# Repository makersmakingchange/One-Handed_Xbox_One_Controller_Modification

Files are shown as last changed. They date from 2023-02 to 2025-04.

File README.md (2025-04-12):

<!--- Open Source Assistive Technology: GitHub Readme Template --->

<!---INSTRUCTIONS  This is a markdown template for creating the README.md file in a GitHub repository. This file is rendered and displayed automatically when someone visits the repository.
This document includes helper text that will not be displayed when rendered. Any text between the less-than sign + exclamation mark + three hyphen-minus (<!---) and matching three hyphen-minus + greater-than sign will not be displayed. This helper text can be deleted once the corresponding section is completed.
--->
 
<!--- TITLE Should match the name of the GitHub repository. Choose something descriptive rather than whimsical.  --->
 # One-Handed Mods for Xbox One Controller

<!--- SUMMARY A brief summary of the project. What it does, who it is for, how much it costs.  --->
This inexpensive 3D printed modification for the Xbox One controller will allow for the user to operate their Xbox One controller with one hand. This controller adaptation makes it easier for someone who may have a difficult time holding a controller with both hands, or has greater dexterity with one hand than the other. The modification is removable; no permanent modifications to the controller are required. There are two versions of the modifier: one for use with the right hand, one for use with the left hand.

<!--- PHOTO  --->
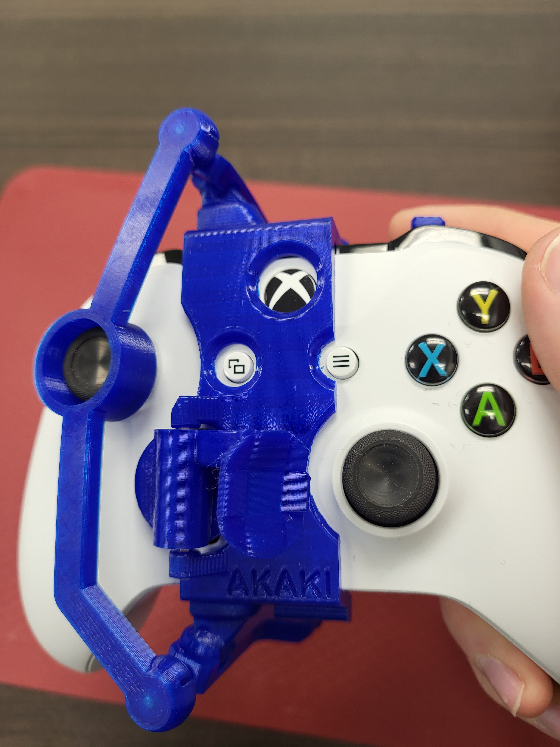
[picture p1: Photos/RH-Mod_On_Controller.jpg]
Right Hand Mod on Xbox One Controller.


## More info at
  - [Makers Making Change Project Page](https://makersmakingchange.com/project/one-handed-mods-for-xbox-one-controller/)

## Getting Started
<!---  Include an overall idea of what major steps are required to build the device.  --->

### 1. Print the 3D Printable components
Print the components for the switch tester case and choose an option for the case.

All of the files and individual print files can be in the [/Build_Files/3D_Printing_Files](/Build_Files/3D_Printing_Files/) folder.

### 2. Assemble the One-Handed Mod for Xbox One Controller
Reference the Assembly Guides in the [Documentation](/Documentation) folder for the tools and steps required to build each portion.

## Files
<!--- FILES This section includes all the information and files required to build and modify the device, including documentation, design files, and build files. --->

### Documentation
<!--- DOCUMENTATION  --->
| Document | Version | Link |
|---|---|---|
| Bill of Materials | 1.0 | [One-Handed_Mods_BOM](/Documentation/Working_Documents/One-Handed_Mods_for_Xbox_One_Controller_BOM.xlsx) |
| Left-Hand Mod Assembly Guide | 1.0 | [Left-Hand_Mod_Instructions](/Documentation/Left-Handed_Mod_for_Xbox_One_Controller_Assembly_Guide.pdf) |
| Right-Hand Mod Assembly Guide | 1.0 | [Right-Hand_Mod_Instructions](/Documentation/Right-Handed_Mod_for_Xbox_One_Controller_Assembly_Guide.pdf) |
| Maker Checklist | 1.0 | [One-Handed_Mods_Checklist](/Documentation/One-Handed_Mods_for_Xbox_One_Controller_Maker_Checklist.pdf) |
| User Quick Guide | 1.0 | [One-Handed_Mods_Quick_Guide](/Documentation/One-Handed_Mods_for_Xbox_One_Controller_User_Guide.pdf) |
| Changelog | 1.0 | [One-Handed_Mods_Changelog](/Documentation/One-Handed_Mods_for_Xbox_One_Controller_Changelog.pdf) |

### Build Files
<!--- BUILD FILES --->
 - [3D Printing Files](/Build_Files/3D_Printing)

## License
<!--- LICENSE Choose an appropriate license. We recommend an open-source hardware compatible license. --->
Everything needed or used to design, make, test, or prepare the One-Handed Mods for Xbox One Controller is licensed under a Creative Commons Attribution-NonCommercial-ShareAlike 4.0 International license.

Accompanying material by Makers Making Change, such as instruction manuals, are published under a Creative Commons Attribution-ShareAlike 4.0 license <https://creativecommons.org/licenses/by-sa/4.0/> (CC BY-SA 4.0).

## Attribution
<!--- ATTRIBUTION Include any information related to the development of the design. This may include who identified the initial challenge, who contributed to the design --->
Designed and remixed by [Akaki](https://www.printables.com/social/106360-akaki/about).

The documentation template was created by Makers Making Change and is used under a CC BY-SA 4.0 license. It is available at the following link: https://github.com/makersmakingchange/OpenAT-Template

----

<!-- ABOUT MMC START -->
## About Makers Making Change
[Makers Making Change Logo](https://www.makersmakingchange.com/)

Makers Making Change is a program of [Neil Squire](https://www.neilsquire.ca/), a Canadian non-profit that uses technology, knowledge, and passion to empower people with disabilities.

Makers Making Change leverages the capacity of community based Makers, Disability Professionals and Volunteers to develop and deliver affordable Open Source Assistive Technologies.

 - Website: [www.MakersMakingChange.com](https://www.makersmakingchange.com/)
 - GitHub: [makersmakingchange](https://github.com/makersmakingchange)
 - Bluesky: [@makersmakingchange.bsky.social](https://bsky.app/profile/makersmakingchange.bsky.social)
 - Instagram: [@makersmakingchange](https://www.instagram.com/makersmakingchange)
 - Facebook: [makersmakechange](https://www.facebook.com/makersmakechange)
 - LinkedIn: [Neil Squire Society](https://www.linkedin.com/company/neil-squire-society/)
 - Thingiverse: [makersmakingchange](https://www.thingiverse.com/makersmakingchange/about)
 - Printables: [MakersMakingChange](https://www.printables.com/@MakersMakingChange)

### Contact Us
For technical questions, to get involved, or to share your experience we encourage you to [visit our website](https://www.makersmakingchange.com/) or [contact us](https://www.makersmakingchange.com/s/contact).
<!-- ABOUT MMC END -->

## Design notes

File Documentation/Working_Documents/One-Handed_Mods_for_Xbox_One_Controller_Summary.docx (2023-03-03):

# Title

One-Handed Mods for Xbox One Controller

## Subtitle

3D printed Modifications to make an Xbox One controller accessible with either your right or left hand only.

## Device Specifications

Build Time:

< 1hr

1-4 hr

5-10hr

>10hr

Cost:

$0 - $10

$11 - $25

$26 - $50

$51 - $100

$101 - $250

$250+

Stage:

Skills:

Need:

Disability:

Difficulty:

License:

Usages:

Type:

Designer:

## Device Details

### Overview

This inexpensive 3D printed modification for the Xbox One controller will allow for the user to operate their Xbox One controller with one hand. This controller adaptation makes it easier for someone who may have a difficult time holding a controller with both hands, or has greater dexterity with one hand than the other.

### Compatibility

Note that the Xbox controllers can be used on PC based gaming and can be used with a Nintendo Switch with the correct adapter.

Platforms: Xbox Series X|S, Xbox One, Xbox 360, PC, Nintendo Switch (with a similar adapter (https://www.amazon.ca/Mayflash-Magic-NS-Wireless-Controller-Nintendo/dp/B079B5KHWQ?hvadid=292937839648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)).

Controllers: Xbox One Controllers

### Usage

This controller adaptation allows for the user to operate their Xbox Series X|S controller with only one hand. For a left handed controller, the right joystick is used by moving the whole controller. By moving the controller, the 3D printed parts enable the joystick to move simultaneously. In addition, the right shoulder buttons are migrated to the left side so all four shoulder buttons can be used with the index finger. Similarly, four 3D printed arms are used to allow the user to press the A, B, X, Y, and home buttons from the left side.

There are two different attachments for the bottom of the controller shown below that can be used depending on whether the user chooses to strap the controller to their leg (right), or can rest it on their lap or a surface of their choice using the “shoe” (left).

### Build Instructions

#### A set of instructions for assembling this modification for the Xbox One controller can be found through our GitHub Repository and through the YouTube assembly video (https://www.youtube.com/watch?v=QOOU2KnhcHA) linked above.

#### The Xbox One controller is asymmetrical, so this controller modification has different files for the left and right-handed modifications.

#### Skills Required

- 3D printing

#### Tools

- 3D printer
- Scissors

Optional:

- Rubber bands can be added to the bottom piece of the controller (shoe) to increase grip strength.
- Raw filament can be cut and used as pin joints between some of the pieces.
- Sandpaper to smooth the ball and socket joints.
- Vaseline to lubricate the ball and socket joints.

#### 3D Printing

All components can be printed with no support at 20% infill with a 0.2mm layer height. All pieces can be printed using PLA filament. If possible, it is recommended to print the “shoe” piece in TPU, but if printed in PLA add rubber bands around the piece for additional grip. 3D print files can be found on the Prusa Printers’ website and are linked above.

Note that all necessary components for the left and right-handed modifications (including the leg mount) are included in their respective print files.

Optional files:

- 1x Shoe (optional replacement to leg mount)
- 1x Button Decorations (optional and only for the left handed modification)

### Attribution

Designed and Remixed from the Xbox Series X|S mod (https://makersmakingchange.com/project/one-handed-mod-xbox-series-xs-controller/) by: Akaki (https://www.prusaprinters.org/social/106360-akaki/about)

Released under Creative Commons Attribution-Noncommercial-ShareAlike 4.0 International license.

© 2022 by <Author>. This work is licensed under the CC BY SA 4.0 License: http://creativecommons.org/licenses/by-sa/4.0 Files available at <Replace with MMC Library Link> Page 1 of 2

V1.0 | February 2023 One-Handed Mod for Xbox One Controller Summary

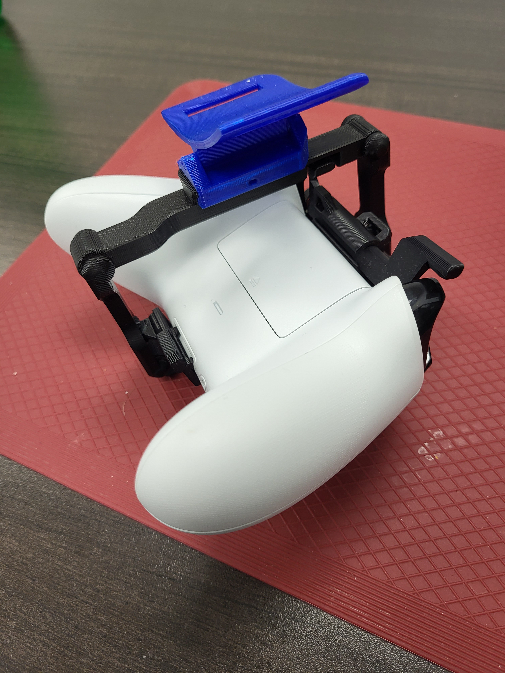
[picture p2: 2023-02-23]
Photos/LH-Mod_With_Leg_Mount.jpg

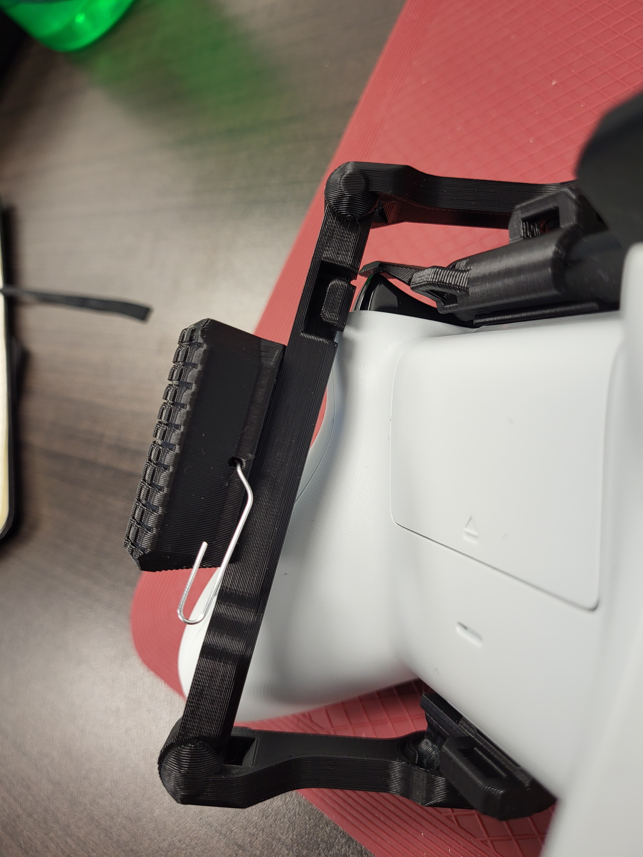
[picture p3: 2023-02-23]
Photos/LH-Mod_With_Shoe.jpg

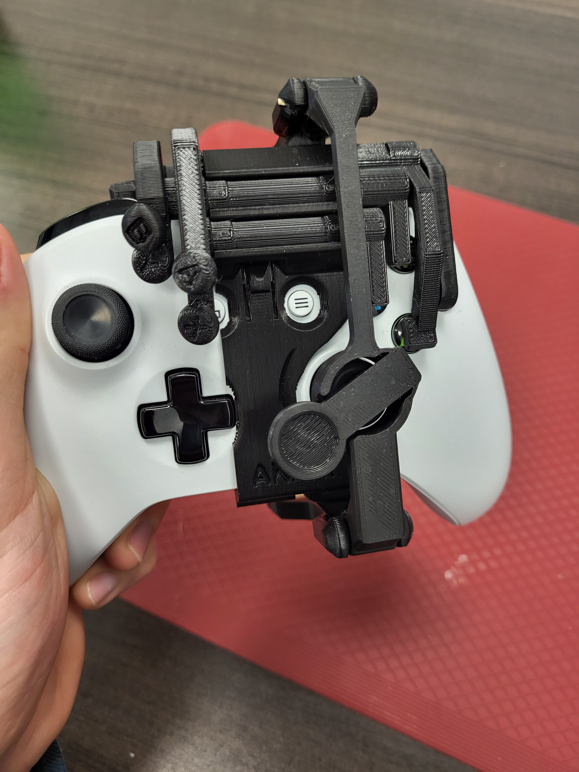
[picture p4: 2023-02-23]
Photos/LH-Mod_On_Controller.jpg

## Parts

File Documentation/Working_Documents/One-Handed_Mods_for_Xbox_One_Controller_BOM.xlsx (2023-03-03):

One-Handed Mods for Xbox One Controller |  |  |  |  |  |  |  | Unit Cost | Total Cost | Total Print time (hr) | Total filament (g)
Version: V1.0 |  | Last Updated: 2023-02-23 |  |  |  |  |  | $3.43 | $0.00 | 0.00 | 137.31
Commercial Parts
ID | Part Name | Part Type | QTY | QTY/PKG | $/PKG | PKG QTY | $/Unit | Extended | Total | Link
 |  |  |  |  | $0.00 | 0 | $0.00 | $0.00 | $0.00
 |  |  |  |  | $0.00 | 0 | $0.00 | $0.00 | $0.00
 |  |  |  |  | $0.00 | 0 | $0.00 | $0.00 | $0.00
 |  |  |  |  | $0.00 | 0 | $0.00 | $0.00 | $0.00
 |  |  |  |  | $0.00 | 0 | $0.00 | $0.00 | $0.00
 |  |  |  |  | $0.00 | 0 | $0.00 | $0.00 | $0.00
 |  |  |  |  | $0.00 | 0 | $0.00 | $0.00 | $0.00
3D Printed Parts ESTIMATED PRICING USING 1KG ROLL COST: |  | $25.00
ID | Part | Material | QTY | Mass (g) / Unit | Time / Unit |  | Print Time (Min) | Estimated Price |  | Link
 | Left-Handed Mod | PLA | 1 | 66.56 | 7h13m |  | 7h13m | $1.66
 | Right-Handed Mod | PLA | 1 | 45.26 | 4h46m |  | 4h46m | $1.13
 | Shoe | PLA | 1 | 11.62 | 1h22m |  | 1h22m | $0.29
 | Leg Mount | PLA | 1 | 13.87 | 1h26 |  | 1h26 | $0.35
 |  |  |  |  |  |  |  | $0.00
 |  |  |  |  |  |  |  | $0.00
Custom Printed Circuit Board (PCB)
ID | Part |  | QTY
Tools for Assembly
 | Glue
Alternatives (if there are other sources for some parts link them below)
ID | Part and description |  |  |  |  |  |  |  |  | Link

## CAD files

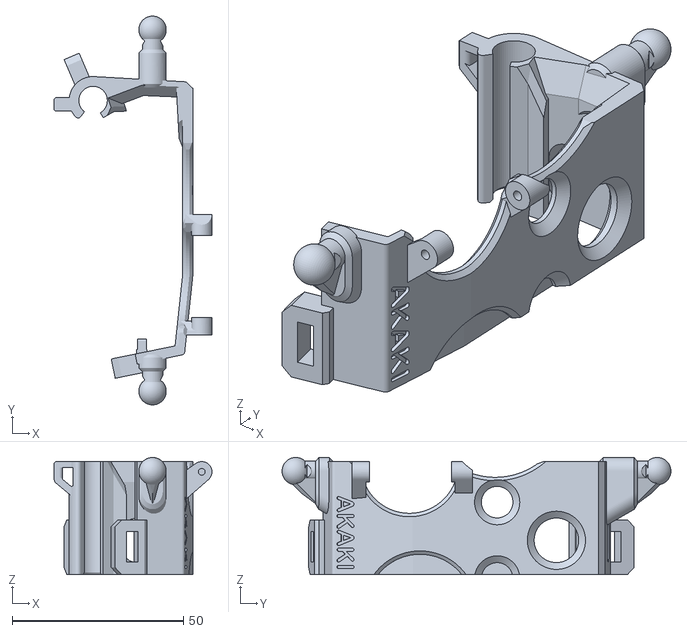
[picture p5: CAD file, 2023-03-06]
Build_Files/3D_Printing_Files/Right-Handed Mod/RH-Main_Housing_Piece.stl
46.2 x 113.6 x 34.2

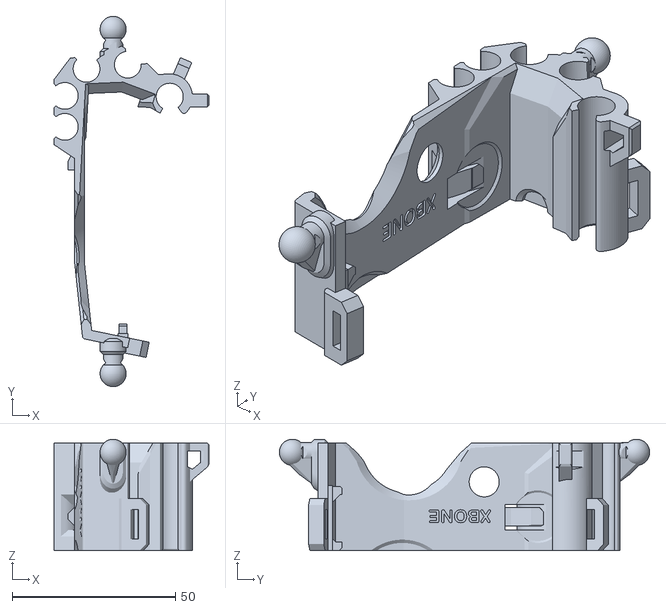
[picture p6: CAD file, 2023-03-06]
Build_Files/3D_Printing_Files/Left-Handed Mod/LH-Main_Housing_Piece.stl
47.5 x 113.6 x 34.2

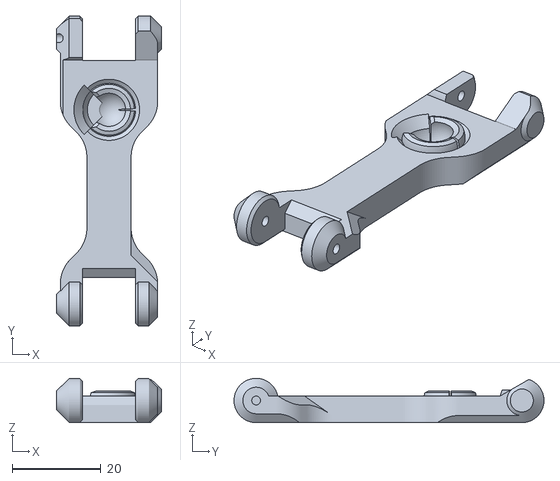
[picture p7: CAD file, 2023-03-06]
Build_Files/3D_Printing_Files/Left-Handed Mod/LH-Top_Ball_n_Socket_Connector.stl
23.6 x 70.0 x 10.00

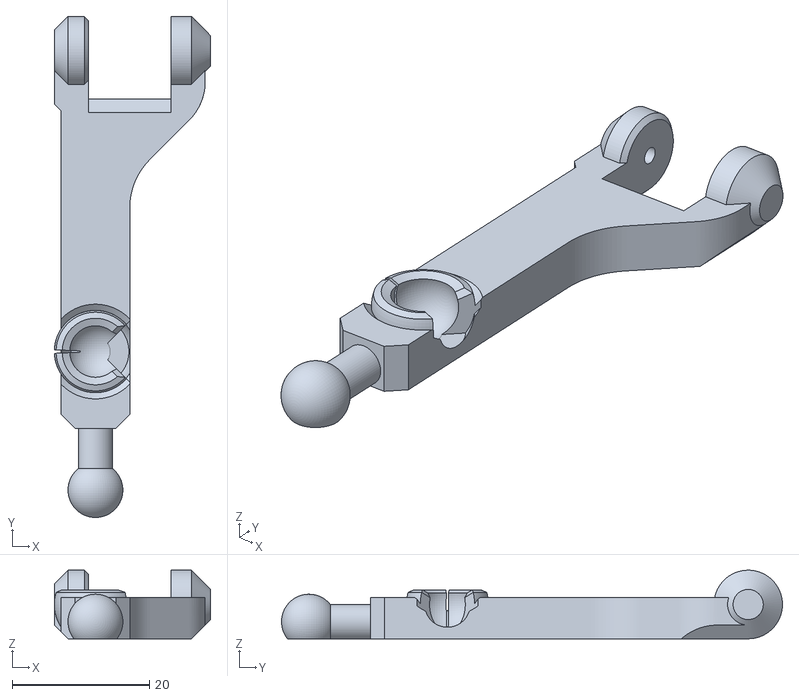
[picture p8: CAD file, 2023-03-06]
Build_Files/3D_Printing_Files/Right-Handed Mod/RH-Bottom_Ball_n_Socket_Connector.stl
22.8 x 73.0 x 10.00

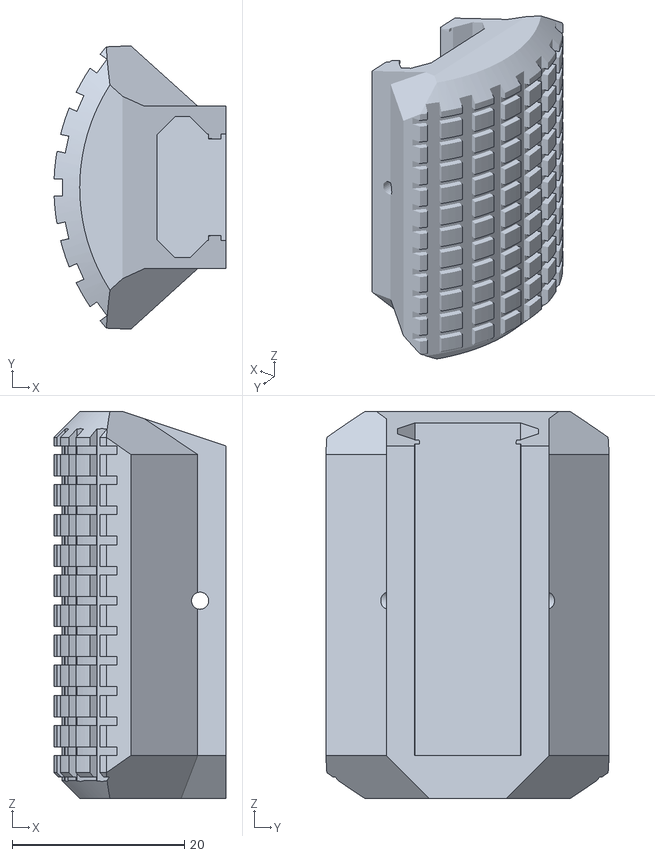
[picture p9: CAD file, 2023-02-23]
Build_Files/3D_Printing_Files/shoe.stl
20.0 x 33.0 x 45.0

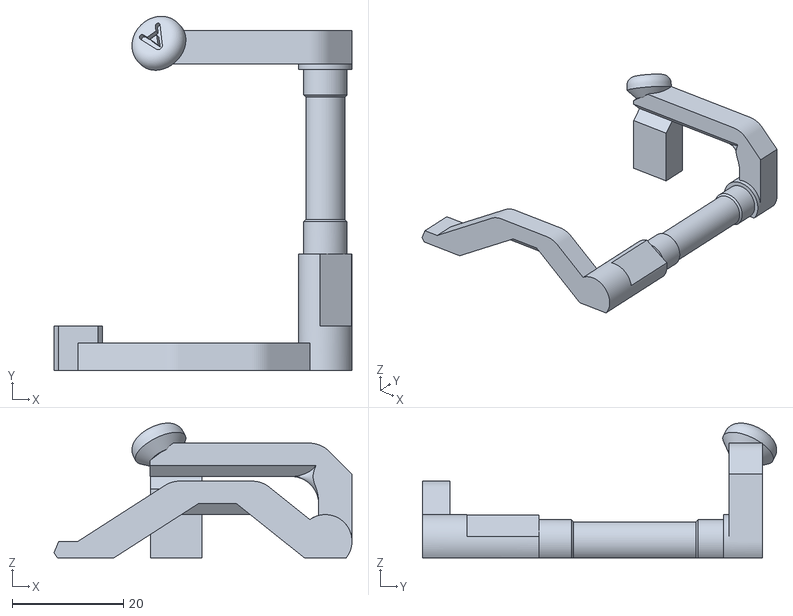
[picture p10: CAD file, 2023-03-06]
Build_Files/3D_Printing_Files/Left-Handed Mod/LH-A_Button_Extender.stl
53.6 x 63.8 x 24.3

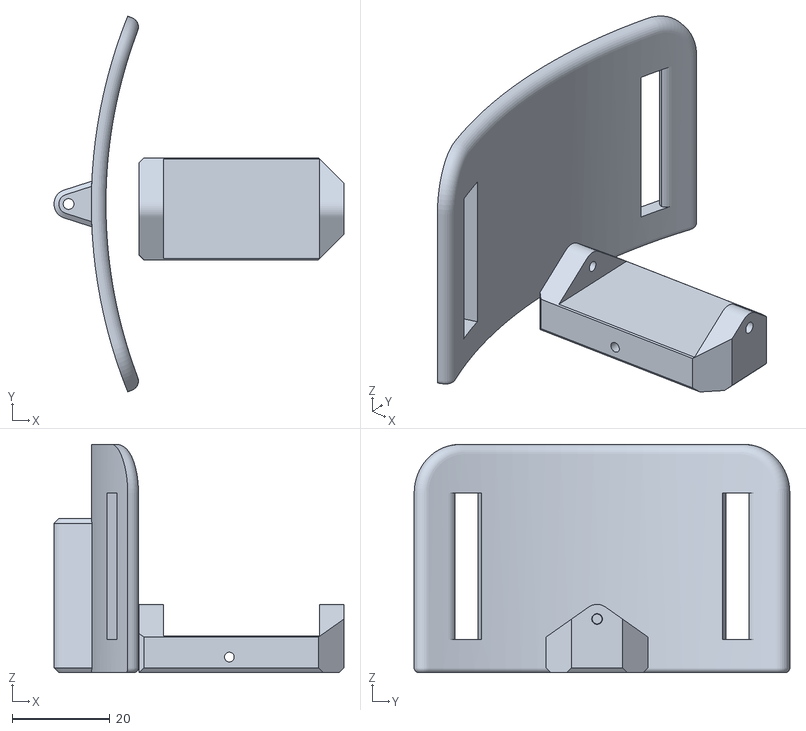
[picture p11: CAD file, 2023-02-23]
Build_Files/3D_Printing_Files/leg mount.stl
59.4 x 77.0 x 46.8

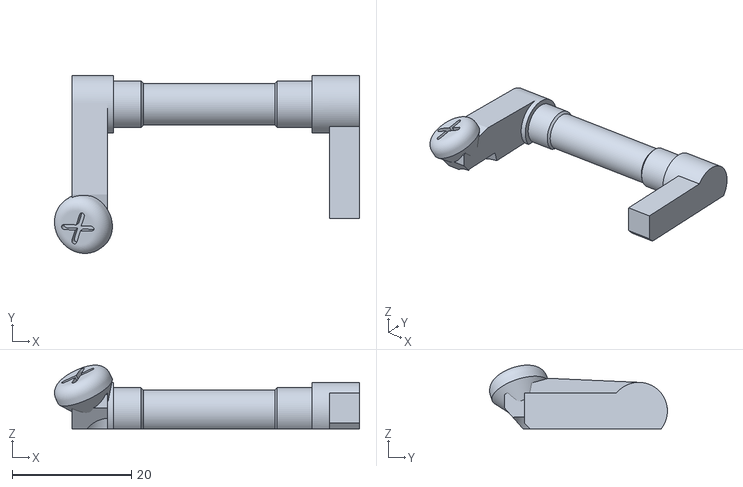
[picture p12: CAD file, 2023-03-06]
Build_Files/3D_Printing_Files/Left-Handed Mod/LH-X_Button_Extender.stl
51.1 x 29.8 x 10.7

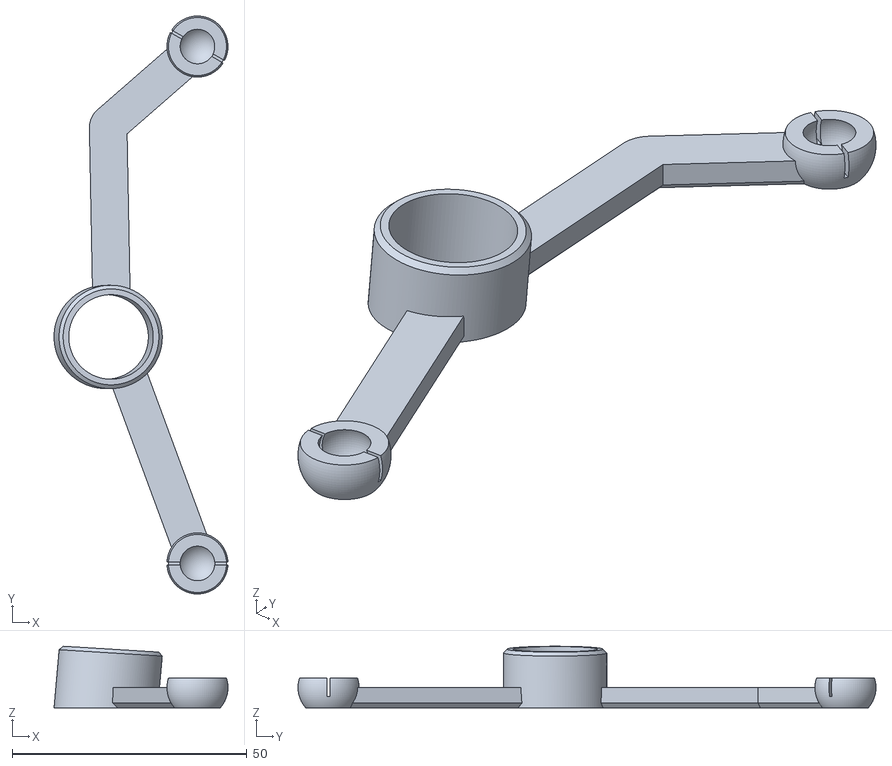
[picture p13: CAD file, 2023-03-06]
Build_Files/3D_Printing_Files/Right-Handed Mod/RH-Thumstick_Arm.stl
37.0 x 123.0 x 13.1

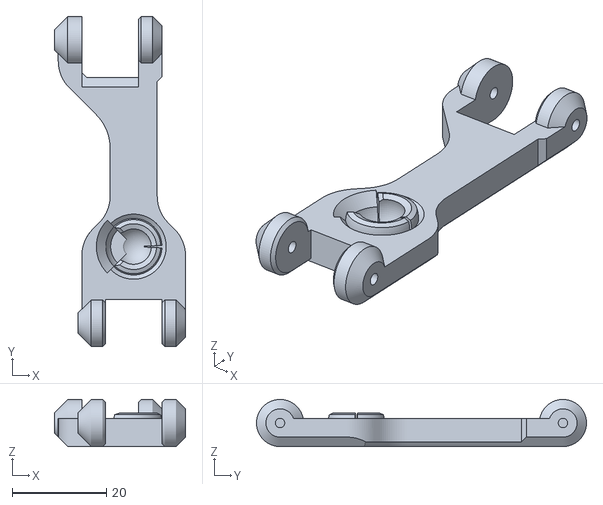
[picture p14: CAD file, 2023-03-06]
Build_Files/3D_Printing_Files/Left-Handed Mod/LH-Bottom_Ball_n_Socket_Connector.stl
27.8 x 70.0 x 10.00

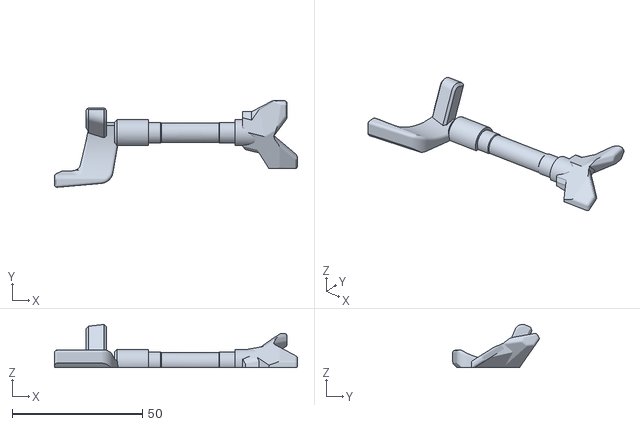
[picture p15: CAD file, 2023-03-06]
Build_Files/3D_Printing_Files/Right-Handed Mod/RH-Trigger_Extender.stl
93.2 x 33.2 x 16.5

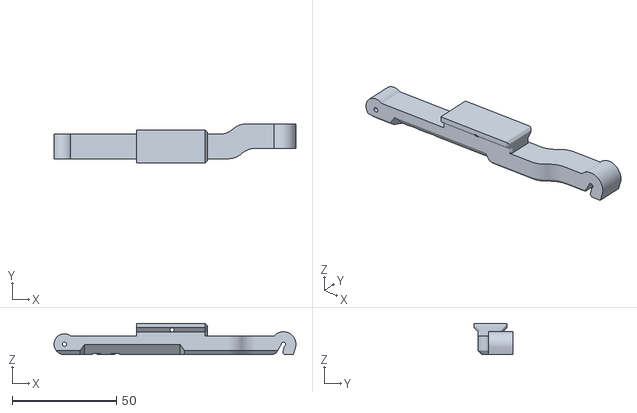
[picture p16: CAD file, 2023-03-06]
Build_Files/3D_Printing_Files/Left-Handed Mod/LH-Rear_Connecting_Arm.stl
116.0 x 18.9 x 15.0

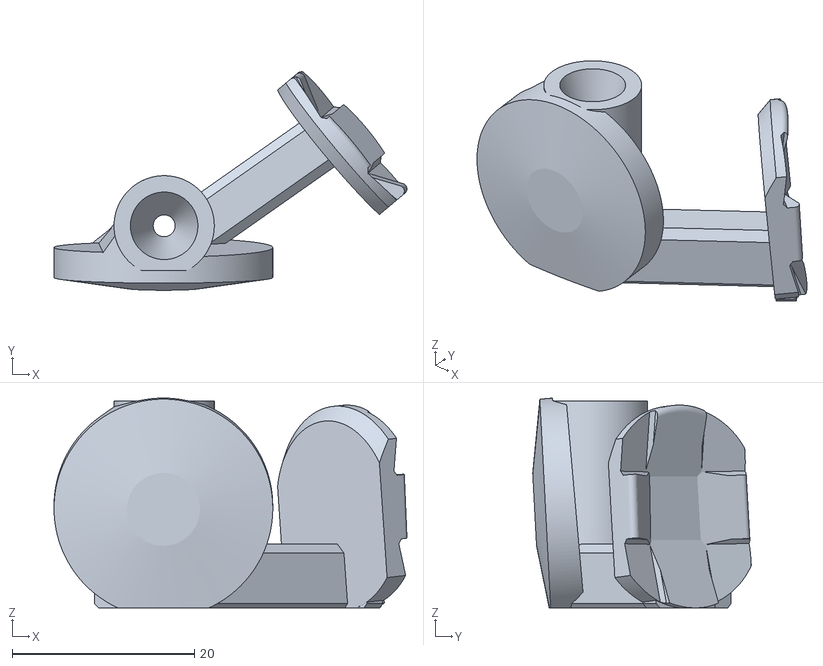
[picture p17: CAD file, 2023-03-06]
Build_Files/3D_Printing_Files/Right-Handed Mod/RH-Dpad_Extender.stl
38.7 x 24.0 x 23.0

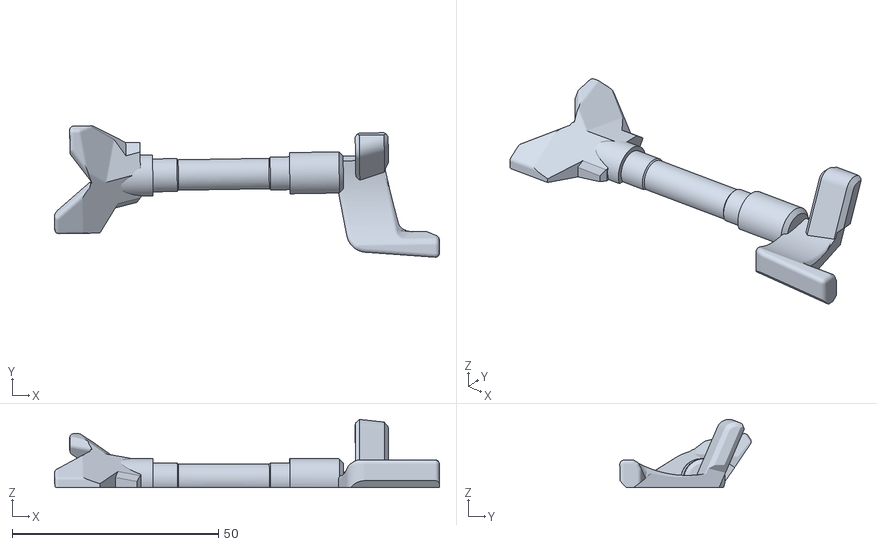
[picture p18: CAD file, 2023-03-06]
Build_Files/3D_Printing_Files/Left-Handed Mod/LH-Trigger_Extender.stl
93.4 x 31.9 x 16.5

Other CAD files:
Build_Files/3D_Printing_Files/Right-Handed Mod/RH-Top_Ball_n_Socket_Connector.stl
Build_Files/3D_Printing_Files/Right-Handed Mod/XBONE right handed.stl
Build_Files/3D_Printing_Files/Left-Handed Mod/LH-Y_Button_Extender.stl
Build_Files/3D_Printing_Files/Left-Handed Mod/LH-Thumbstick_Arm.stl
Build_Files/3D_Printing_Files/Left-Handed Mod/LH-B_Button_Extender.stl
Build_Files/3D_Printing_Files/Left-Handed Mod/XBONE left handed.stl

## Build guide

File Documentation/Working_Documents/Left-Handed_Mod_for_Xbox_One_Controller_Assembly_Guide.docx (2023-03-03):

# Required Components

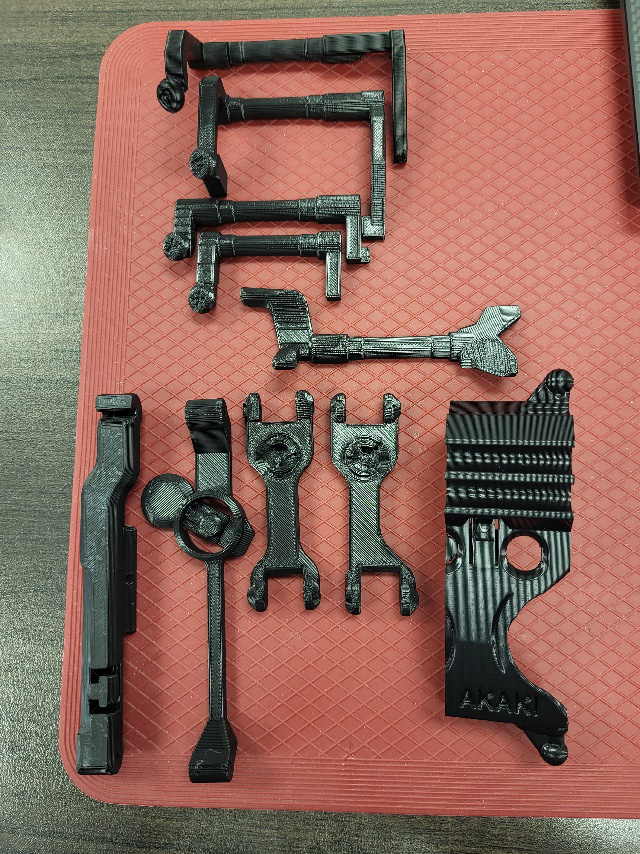
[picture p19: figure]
A picture containing the 10 black 3D printed components for a left-handed Xbox One controller mod.

10 9 8 7 6 5 4 3 2 1 | BOM 1. B Button Extender 2. A Button Extender 3. Y Button Extender 4. X Button Extender 5. Trigger Extender 6. Rear Connecting Arm 7. Thumbstick Arm 8. Top Ball n Socket Connector 9. Bottom Ball n Socket Connector 10. Main Housing Piece 11. Pins (extra filament)

# Required Tools

- Glue

# Required Personal Protective Equipment (PPE)

- Safety Glasses

# Assembly Instructions

## Step 1

Take the button extenders and push the middle shaft section into the outward facing slots on the main housing piece. From bottom to top, the order is X, Y, A, B. The side with the buttons will end up on the left-hand side, while the blank ends will end up on the right-hand side to cover the actual controller buttons. Note: The second photo shows the main housing piece on the controller, this is not required, but may aid in situating the pieces in the correct order. The mod will have to be removed from the controller for Step 2.

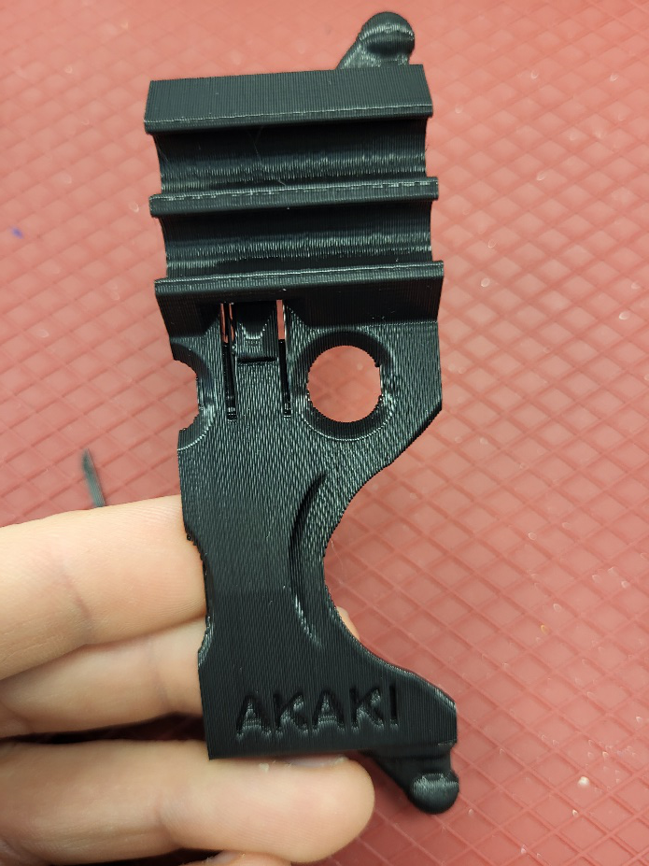
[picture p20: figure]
A picture containing the balck 3D printed main housing piece of the controller mod.
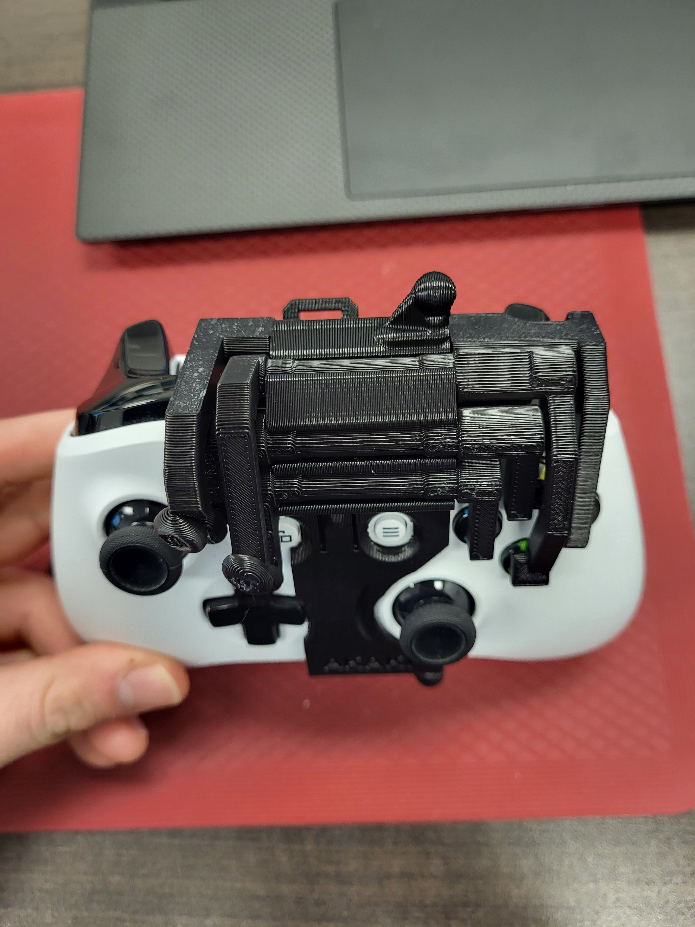
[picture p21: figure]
A picture showing the button extenders attached to the main housing piece of the controller mod printed in black PLA on a white Xbox One controller.

B

A

Y

X

Slots

## Step 2

Take the trigger/bumper extender and snap it into the remaining slot on the back of the main housing piece. Ensure the larger side is on the left when looking from the front, the same orientation as the Prusaslicer rendering shown.

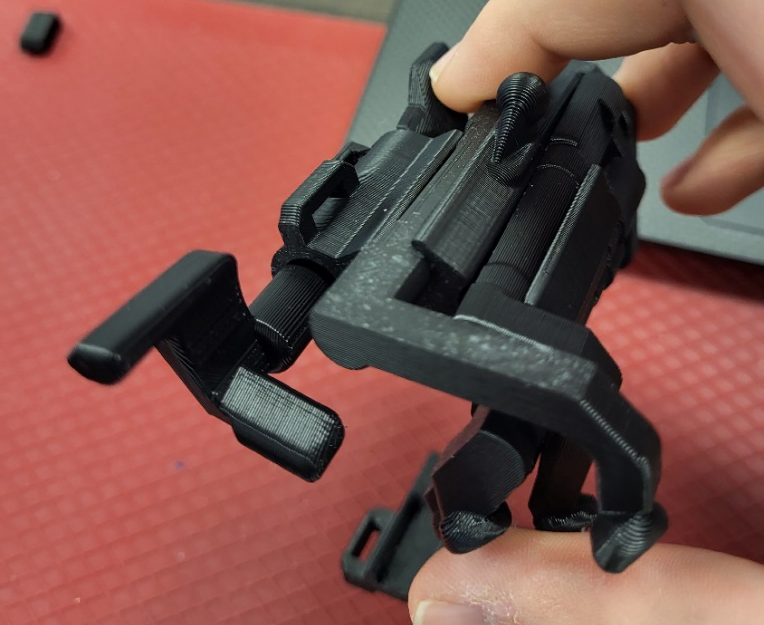
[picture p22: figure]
A picture showing the trigger extenders attached to the main housing piece of the controller mod all 3D printed in black PLA.
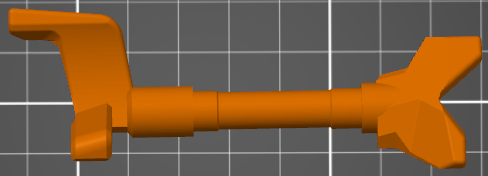
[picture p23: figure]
A screenshot of a rendering of the trigger extender in Prusaslicer, oriented correctly as viewed from the front.

## Step 3

Clip the main housing piece onto the Xbox One controller. Do this by lining up the “view” and “menu” buttons on the front of the controller with the cut-outs on the housing piece, then pushing the bottom clip under the bottom of the controller. It should snap into place.

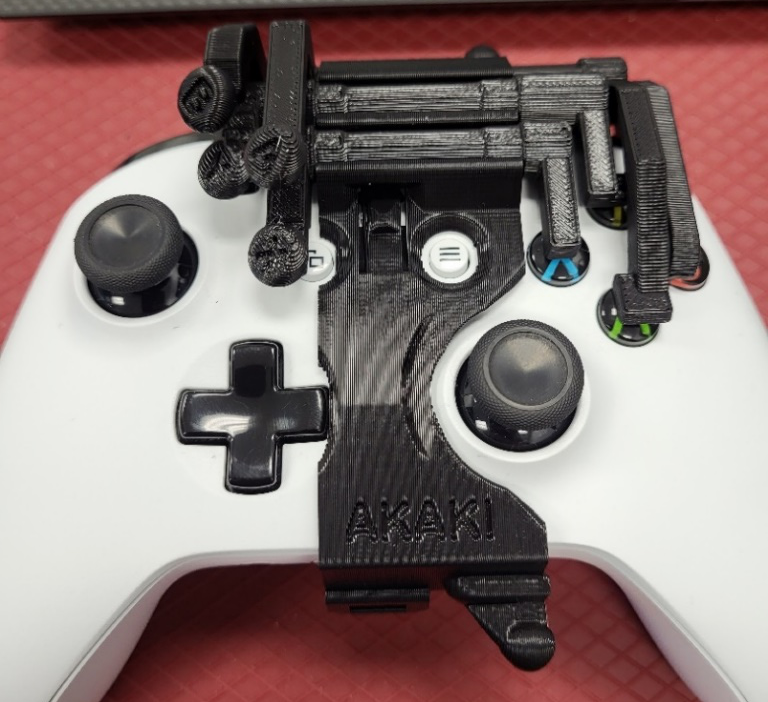
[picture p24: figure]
A picture showing the main housing, button and trigger extenders of the controller mod 3D printed in black PLA on a white Xbox One controller.

## Step 4

Take the pieces with socket joint connections on them. Notice that the two pieces are slightly different, the left-hand one being lined up, while the right-hand side one has the two ends offset from each other. The left-hand piece pictured gets snapped onto the ball joint on the top side of the controller mod, and the right-side piece is snapped onto the ball joint along the bottom of the controller mod, such that the longer ends point toward the back of the controller.

Lined up

Offset

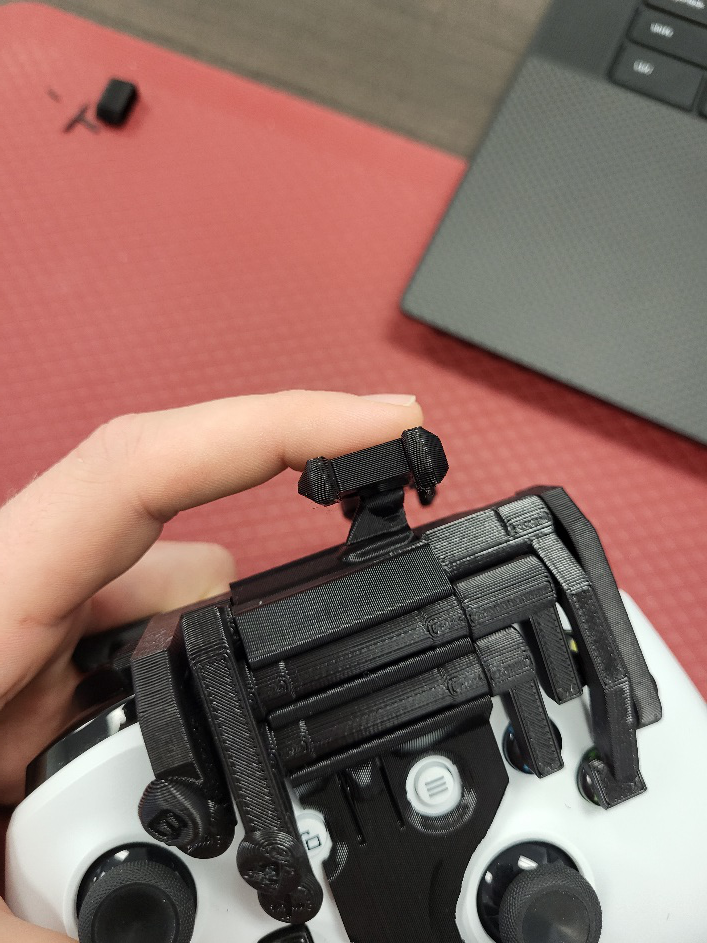
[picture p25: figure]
A picture showing how to attach the ball and socket joint connecting piece to the top of the controller mod.
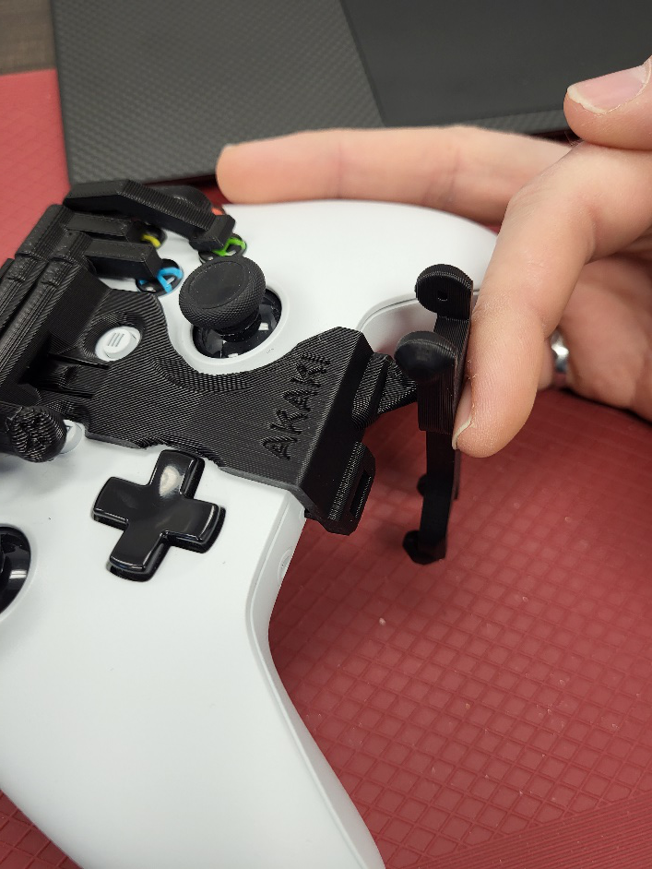
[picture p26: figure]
A picture showing how to connect the ball and socket connecting piece to the bottom of the controller mod.

## Step 5

Attach the thumbstick over the top of the controller using scrap filament, shaved-down toothpicks, or equivalent as pins. Glue the pins in place and cut them down flush to the 3D print. Be careful not to get any glue in the moving portion of this hinge.

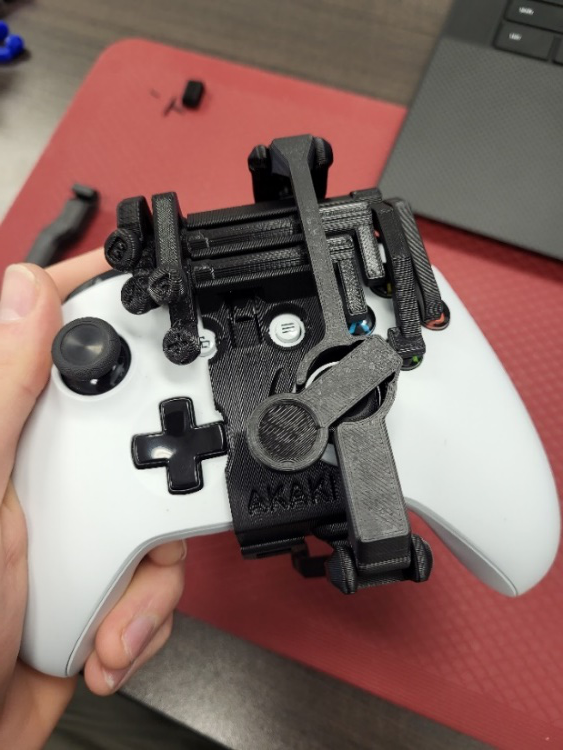
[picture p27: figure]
A picture showing how to position the thumbstick arm on the controller mod fixed to a white Xbox One controller.
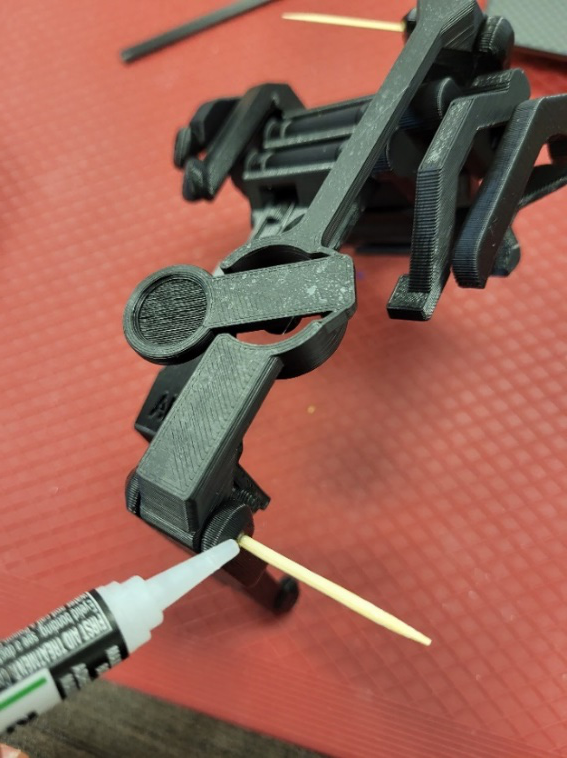
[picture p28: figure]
A picture showing gluing a toothpick pin in place to connect the thumbstick arm to the controller mod.

## Step 6

Attach the remaining connecting rod along the back of the controller such that the open latch end swings to the bottom of the controller.

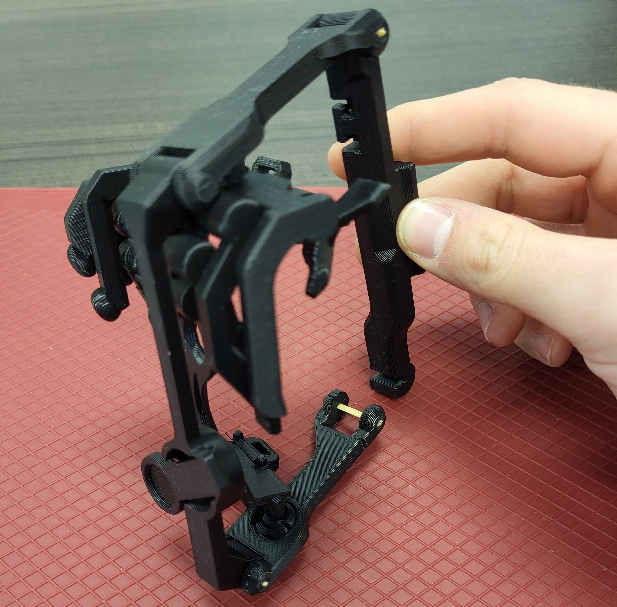
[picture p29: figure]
A picture showing the completed controller mod printed in black PLA

© 2023 by Makers Making Change. This work is licensed under the CC BY SA 4.0 License: http://creativecommons.org/licenses/by-sa/4.0 Files available at https://makersmakingchange.com/project/one-handed-mods-for-xbox-one-controller Page 1 of 1

V1.0 | February 2023 Left-Handed Mod for Xbox One Controller Assembly Guide

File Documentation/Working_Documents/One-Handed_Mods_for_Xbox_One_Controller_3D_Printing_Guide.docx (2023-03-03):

# 3D Printing Summary

Metrics | Left-Handed Mod | Right-Handed Mod
Total Print Time (min) | 7:13 | 4:46
Total Number of Components | 10 | 7
Typical Total Mass (g) | 66.56 | 45.26
Typical Number of Print Setups | 1 | 1

# 3D Printing Settings

Print File Name | Qty | Total Print Time (hr:min) | Mass (g) | Infill (%) | Support(Y/N) | Layer Height/ Nozzle Diameter(mm) | Notes (orientation, special settings, etc.)
XBONE left handed.stl | 1 | 7:13 | 66.56 | 20 | N | 0.2/0.4 | - Print in orientation given in STL
XBONE right handed.stl | 1 | 4:46 | 45.26 | 20 | N | 0.2/0.4 | - Print in orientation given in STL

Optional Prints
Shoe.stl | 1 | 1:22 | 11.62 | 20 | N | 0.2/0.4 | - Print in orientation given in STL
Leg mount.stl | 1 | 1:36 | 13.87 | 20 | N | 0.2/0.4 | - Print in orientation given in STL

Note: All files are available to be printed individually as well.

# Customization Options

- The files can be printed in different colours to customize the device to the user’s preference.

# Post-Processing and Quality Print Examples

- Remove the thin sacrificial bridging on the main housing piece as well as the built in supports on the button extenders.

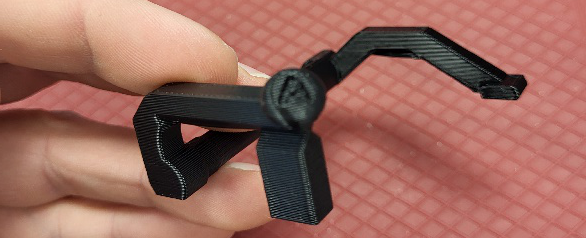
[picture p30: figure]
A picture showing the A button extender with support printed in black PLA.
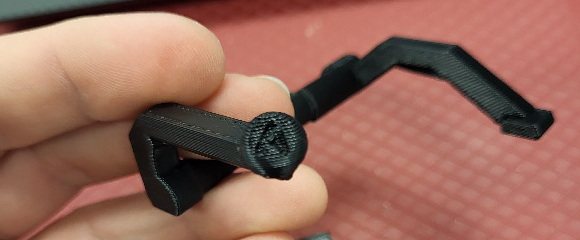
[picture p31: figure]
A picture showing the A button extender without support printed in black PLA.
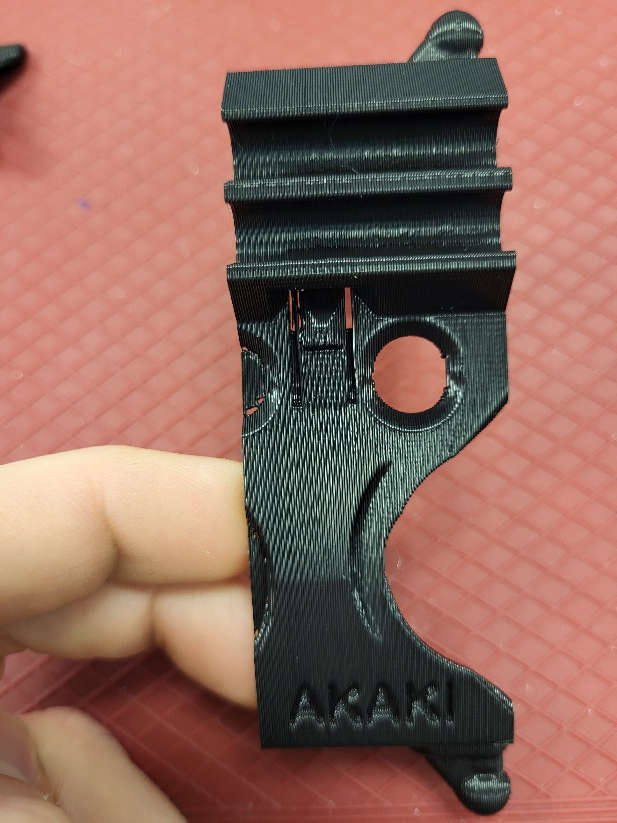
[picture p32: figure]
A picture showing the left-hand controller mod main housing piece with sacrificial bridging printed in black PLA.
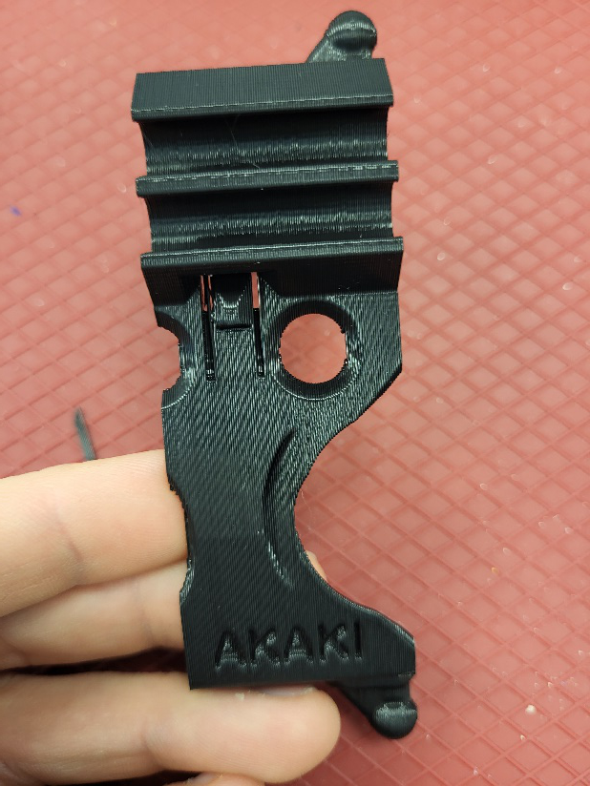
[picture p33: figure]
A picture showing the left-hand controller mod main housing piece without sacrificial bridging printed in black PLA.
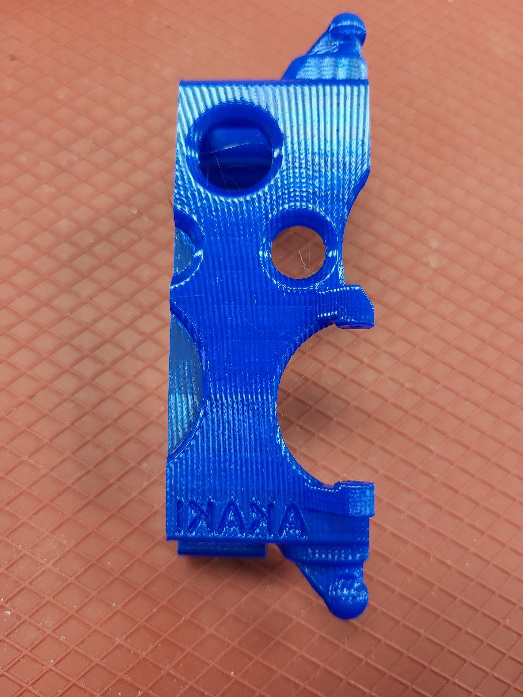
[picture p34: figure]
A picture showing the right-hand controller mod main housing piece with sacrificial bridging printed in blue PLA.
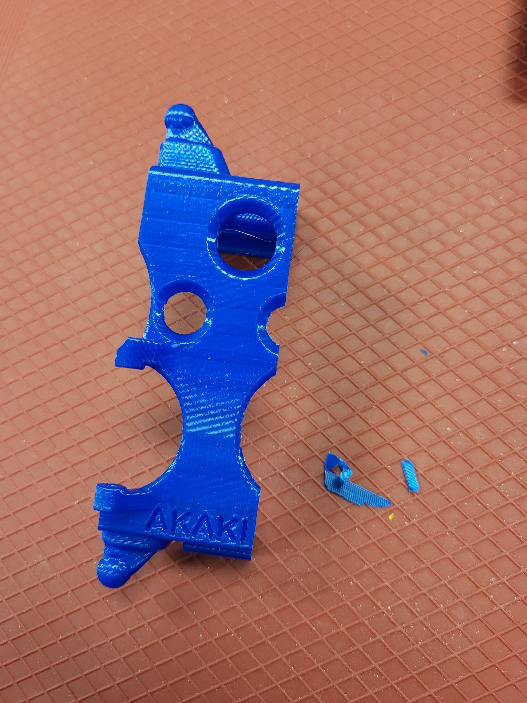
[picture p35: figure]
A picture showing the right-hand controller mod main housing piece without sacrificial bridging printed in blue PLA.

© 2023 by Makers Making Change. This work is licensed under the CC BY SA 4.0 License: http://creativecommons.org/licenses/by-sa/4.0 Files available at https://makersmakingchange.com/project/one-handed-mods-for-xbox-one-controller Page 1 of 2

V1.0 | February 2023 One-Handed Mods for Xbox One Controller 3D Printing Guide

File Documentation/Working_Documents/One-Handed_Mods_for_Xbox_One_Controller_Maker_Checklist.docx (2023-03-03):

# Maker To Do List

- Read through the Assembly Guide to become familiar with required components, tools, supplies, and safety gear and overall assembly steps.
- Talk to User about customization options (e.g., color, any special requests, etc.)
  - Ask user whether they require the left or right-handed mod, or both.
- 3D print parts
- Gather tools, supplies, and safety equipment.
- Assemble the device
- Test device
- Print “User Quick Guide”

# Items to Give to User

- Assembled, tested device
- “User Quick Guide”

© 2023 by Makers Making Change. This work is licensed under the CC BY SA 4.0 License: http://creativecommons.org/licenses/by-sa/4.0 Files available at https://makersmakingchange.com/project/one-handed-mods-for-xbox-one-controller Page 1 of 1

V1.0 | February 2023 One-Handed Mods for Xbox One Controller Maker Checklist

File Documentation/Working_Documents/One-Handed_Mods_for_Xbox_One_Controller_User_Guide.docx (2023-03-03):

## Introduction

The One-Handed Xbox One Controller Mods are intended to give more independent use of an Xbox controller for users with limited function in one of their hands. There is both a left and right-handed model available. This YouTube video (https://www.youtube.com/watch?v=d1hht2D5cvE&t=1s) by the original designer, Akaki, also demonstrates the usage of each device.

## Features

Left-Hand Thumbstick Arm Right-Hand Trigger Extender

Right-Hand Dpad Extender

Left-Hand Trigger Extender

Left-Hand Button Extenders Right-Hand Thumbstick Arm

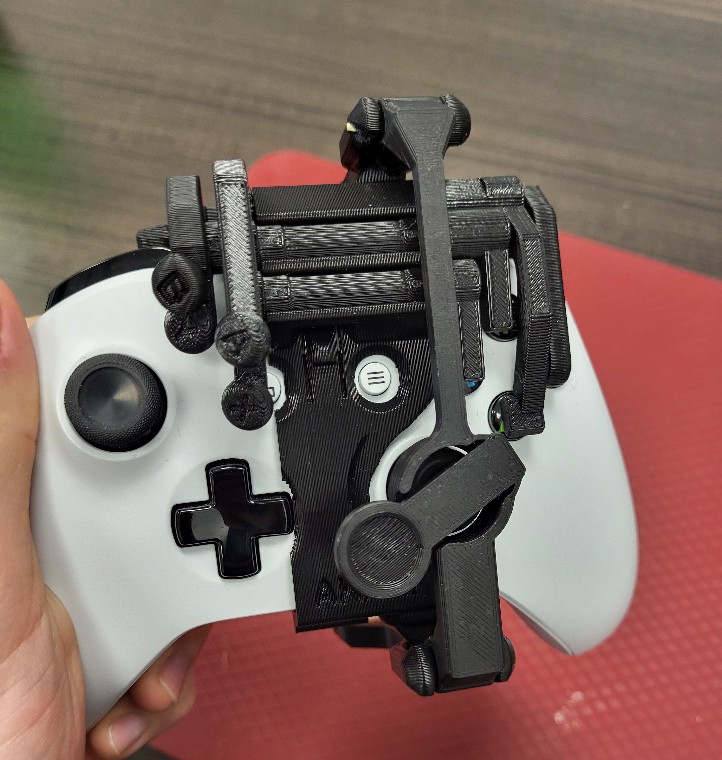
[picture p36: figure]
A picture showing the left-handed controller mod printed in black PLA on a white Xbox One controller with red arrows pointing to specific components.
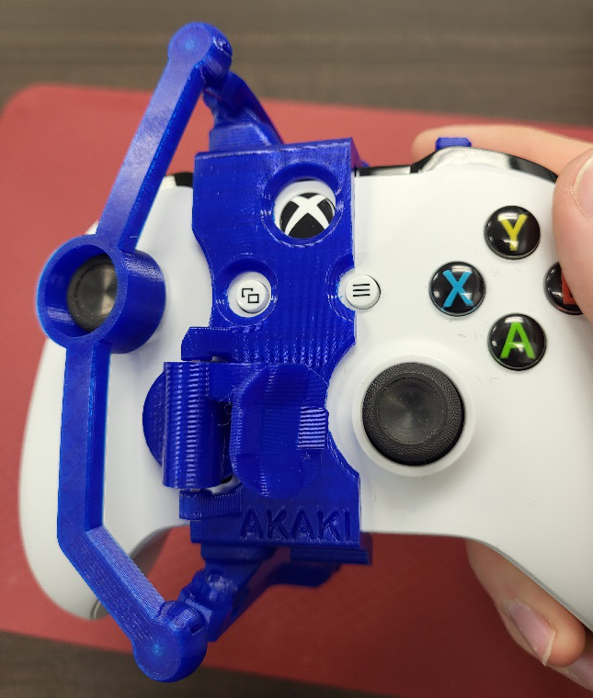
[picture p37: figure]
A picture showing the right-handed controller mod printed in blue PLA on a white Xbox One controller with red arrows pointing to specific components

## Usage

To put the controller mods on, line up the top of the main housing piece with the center of the controller so the button holes line up with the buttons. Then push on the bottom part of the main housing piece to snap it into place. Ensure the thumbstick is centred properly in the circle over the top face of the controller mod. Lastly, latch the arm on the back of the controller mod.

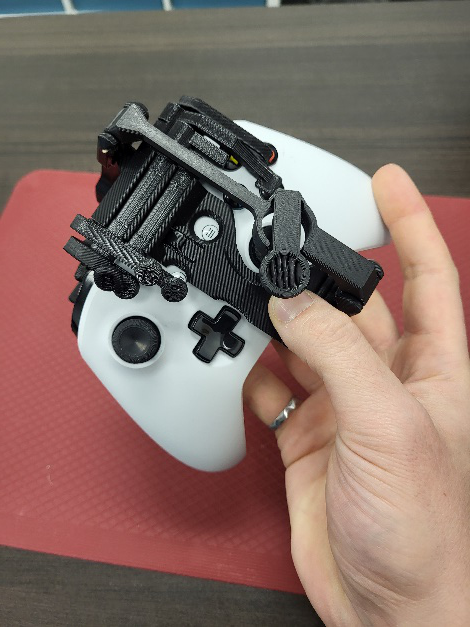
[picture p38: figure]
A picture showing how to snap the left-hand controller mod printed in black PLA to a white Xbox One controller.
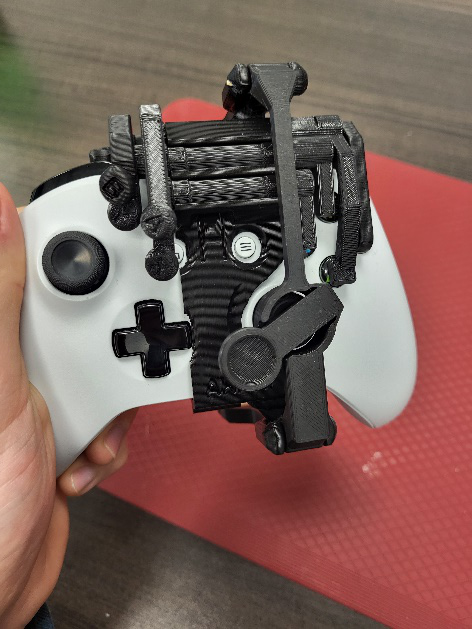
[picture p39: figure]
A picture showing the left-handed controller mod printed in black PLA on a white Xbox One controller.
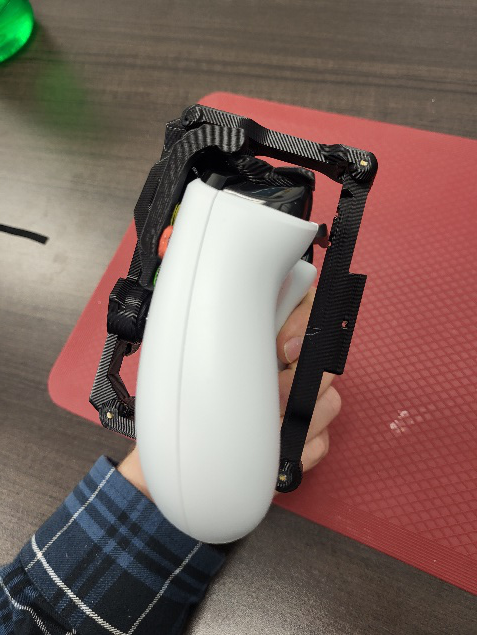
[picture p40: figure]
A picture showing the side view of the left-handed controller mod printed in black PLA on a white Xbox One controller.
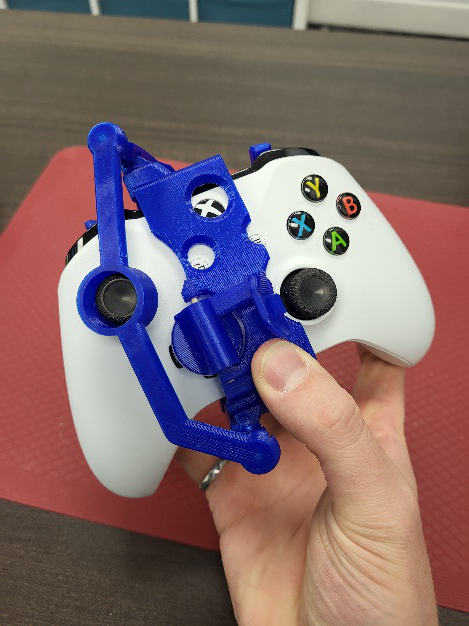
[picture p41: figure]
A picture showing how to snap the right-hand controller mod printed in blue PLA to a white Xbox One controller.
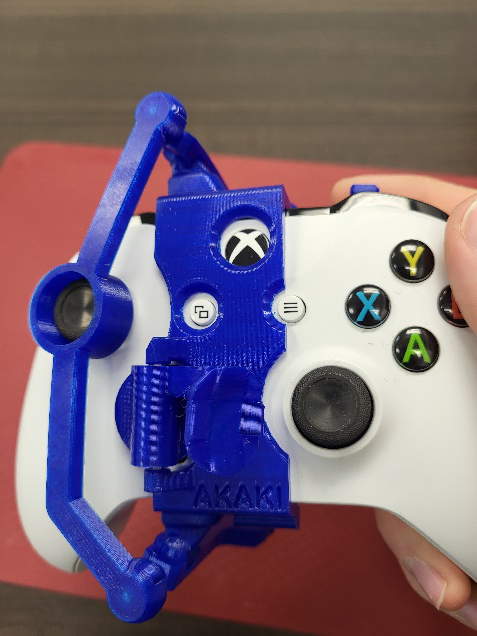
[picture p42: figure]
A picture showing the right-handed controller mod printed in blue PLA on a white Xbox One controller.
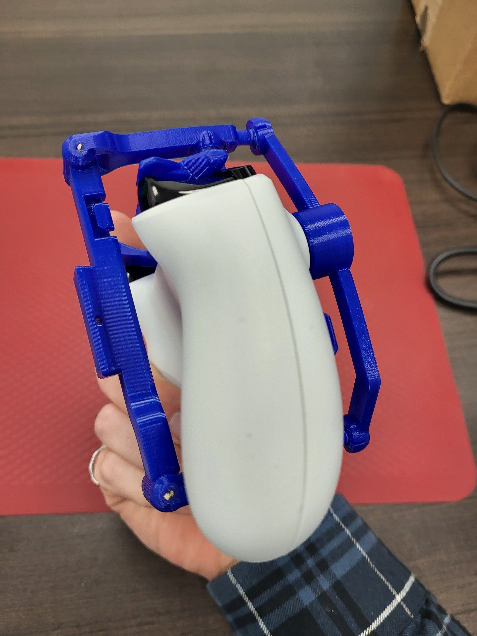
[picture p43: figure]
A picture showing the side view of the right-handed controller mod printed in blue PLA on a white Xbox One controller.

In addition to the mods, there are two mounting methods available. These mounting options both require a pin to fasten them to the controller mod. Extra filament, or a toothpick with glue can be used, or even a bent paperclip for ease of removal. The shoe is a more mobile option, while the leg mount straps the device to the user’s leg in a stationary spot. Moving the controller in respect to this anchor point is what moves the thumbstick, while the button and trigger extenders allow easier reach to the opposite side buttons and triggers.

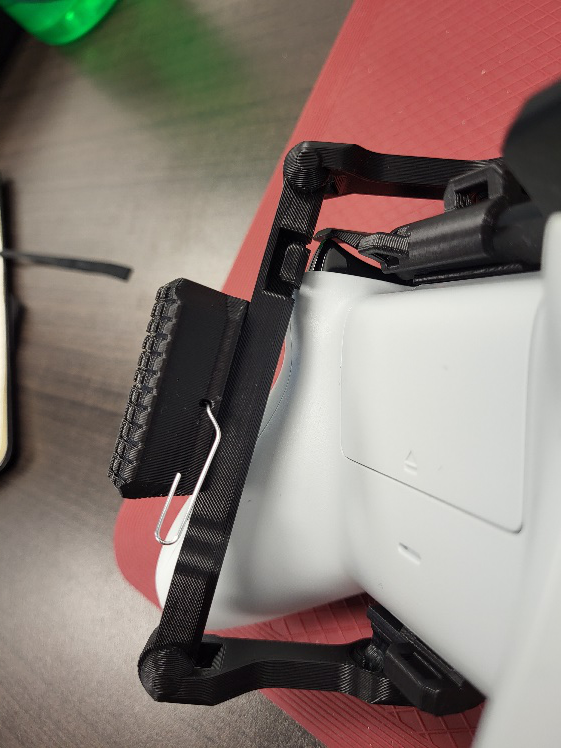
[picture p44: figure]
A picture showing the "shoe" mounting option printed in black PLA connected to the left-hand controller mod printed in black PLA with a bent paperclip on a white Xbox One controller.
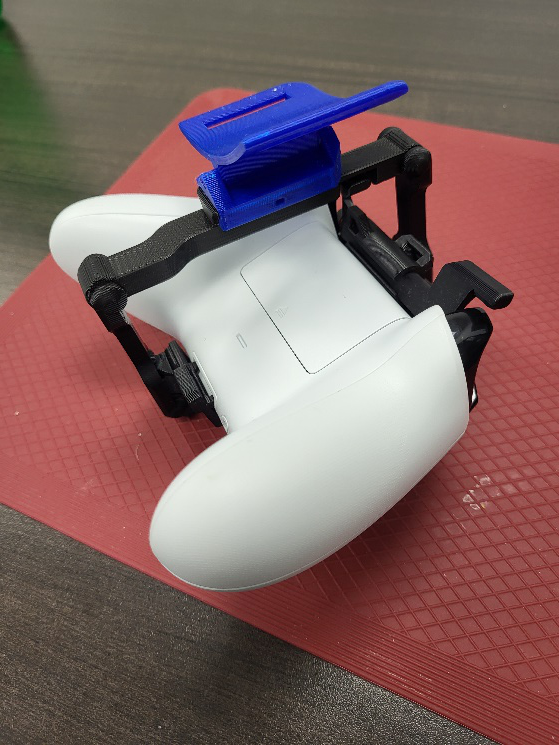
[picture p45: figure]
A picture showing the "leg mount" option printed in blue PLA connected to the left-hand controller mod printed in black PLA on a white Xbox One controller.

Note: The leg mount requires some type of strap (Velcro, elastic webbing, etc.) to fix it to the user’s leg.

## Compatibility

These mods are compatible with the Xbox One controller, which is in turn compatible with the following systems:

- Xbox Series X|S
- Xbox One
- Xbox 360
- PC
- Nintendo Switch (with an appropriate adapter (https://www.amazon.ca/Mayflash-Magic-NS-Wireless-Controller-Nintendo/dp/B079B5KHWQ?hvadid=292937839648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))

## Cleaning

This device can be wiped down with lukewarm water and soap. Do not use hot water as it could cause the plastic to reform.

© 2023 by Neil Squire. This work is licensed under the CC BY SA 4.0 License: http://creativecommons.org/licenses/by-sa/4.0 Files available at https://makersmakingchange.com/project/one-handed-mods-for-xbox-one-controller Page 2 of 3

V1.0 | February 2023 One-Handed Mods for Xbox One Controller user Quick Guide

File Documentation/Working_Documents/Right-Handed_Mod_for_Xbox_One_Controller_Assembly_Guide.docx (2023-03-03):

# Required Components

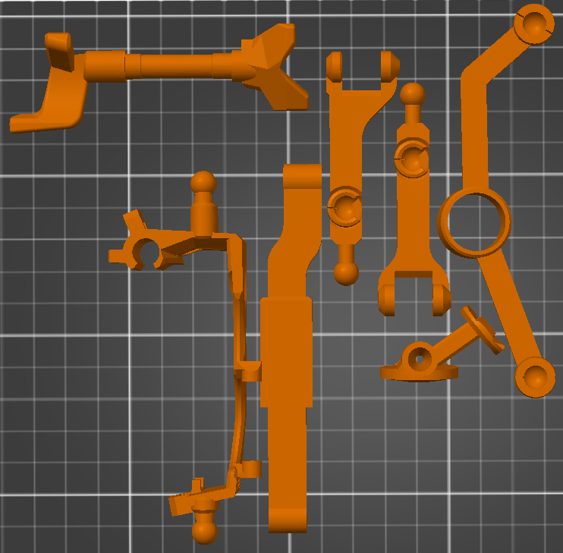
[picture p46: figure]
A screenshot showing the Prusaslicer rendering of the 7 components of the right-handed mod for the Xbox One controller.

7 6 5 4 3 2 1 | BOM 1. Trigger Extender 2. Bottom Ball n Socket Connector 3. Top Ball n Socket Connector 4. Thumbstick Arm 5. Main Housing Piece 6. Rear Connecting Arm 7. Dpad Extender 8. Pins (extra filament)

# Required Tools

- Glue

# Required Personal Protective Equipment (PPE)

- Safety Glasses

# Assembly Instructions

## Step 1

Take the trigger/bumper extender and snap it into the remaining slot on the back of the main housing piece. Ensure the larger side is on the right when looking from the front or top.

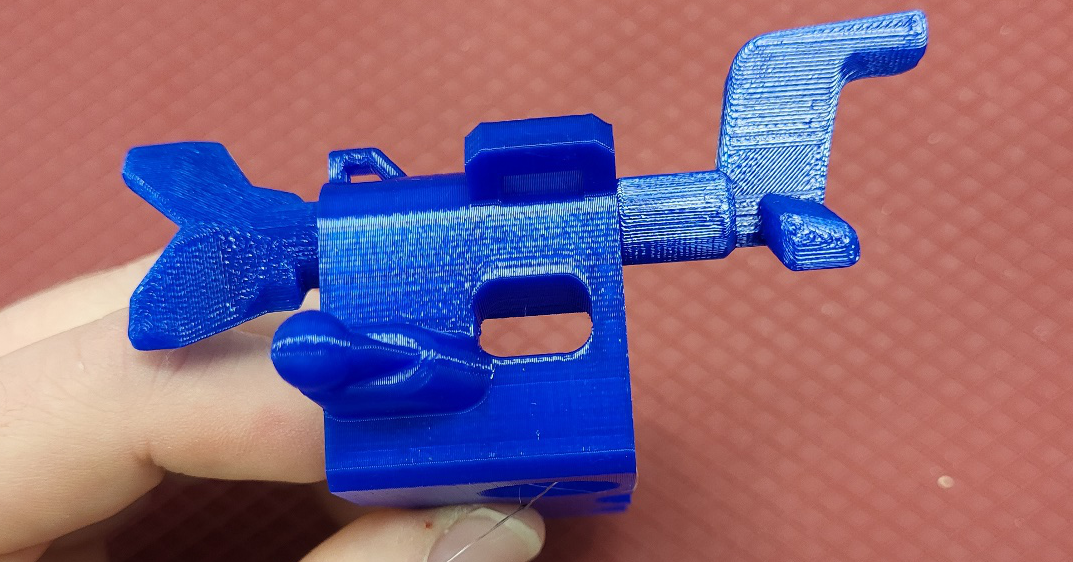
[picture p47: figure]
A picture showing the trigger extender inserted into the main housing piece of the controller mod printed in blue PLA.

## Step 2

Take the pieces with socket joint connections on them. Notice that the two pieces are slightly different, the left-hand one being lined up, while the right-hand side one has the two ends offset from each other. The left-hand piece pictured gets snapped onto the ball joint on the top side of the controller mod, and the right-side piece is snapped onto the ball joint along the bottom of the controller mod, such that the longer ends point toward the back of the controller.

Offset

Lined Up

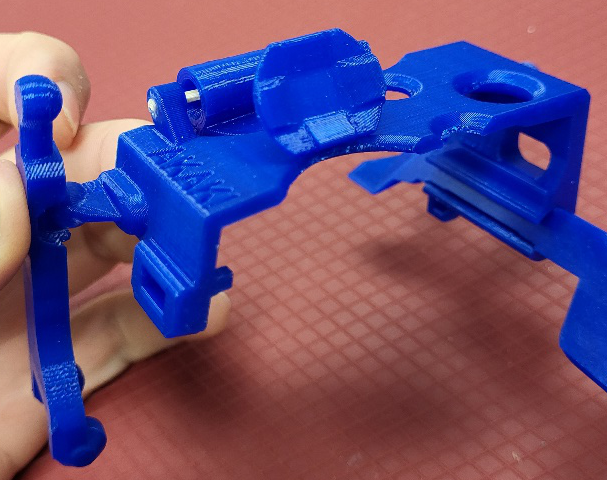
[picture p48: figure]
A picture showing how to attach the ball and socket joint connecting piece to the bottom of the controller mod.
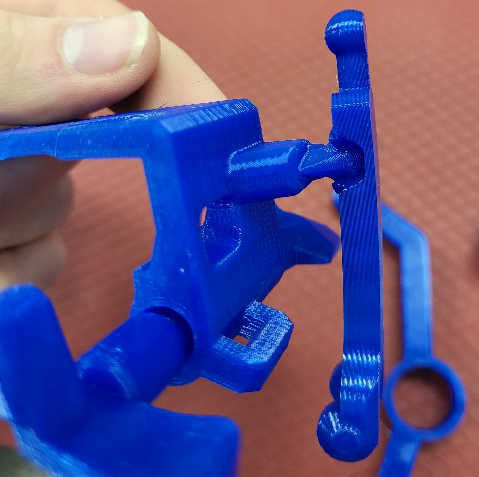
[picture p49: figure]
A picture showing how to attach the ball and socket joint connecting piece to the top of the controller mod.

## Step 3

Clip the thumbstick arm sockets to the ball joints sticking up from Step 2. Ensure the circle lines up with the left thumbstick and is situated toward the top of the controller while the “elbow” corner in this piece is toward the bottom.

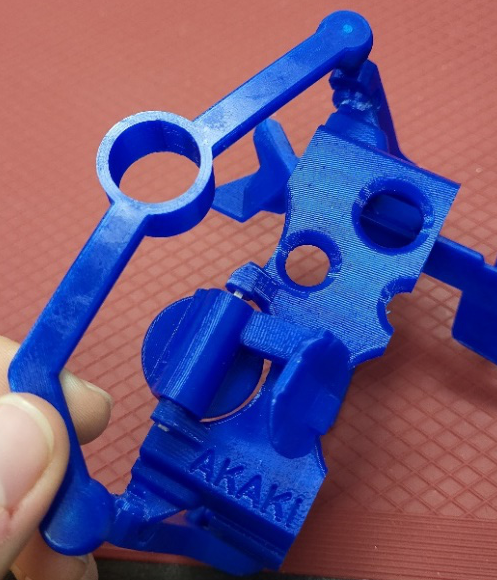
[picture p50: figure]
A picture showing how to attach the thumbstick arm to the controller mod.

## Step 4

Attach the remaining connecting arm along the back of the controller such that the open latch end swings to the bottom of the controller. Use shaved down toothpicks or extra filament and glue to attach the connecting rod.

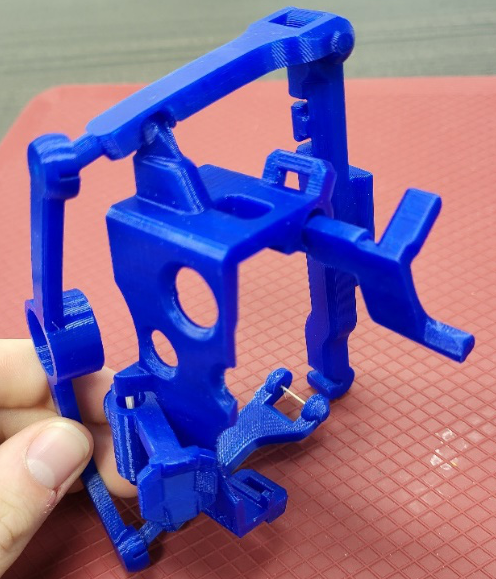
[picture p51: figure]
A picture showing the completed controller mod printed in blue PLA.
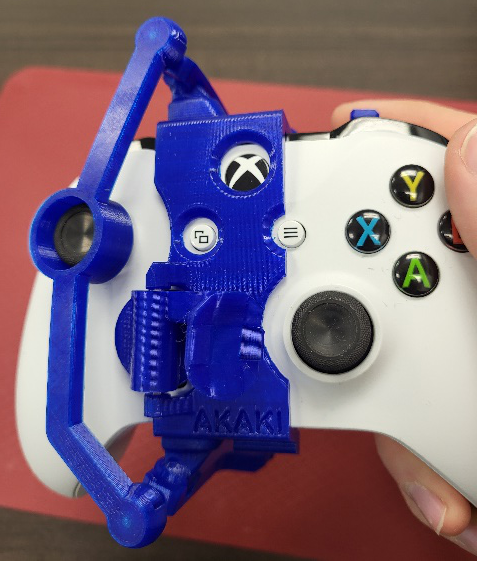
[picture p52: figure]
A picture showing the right-handed controller mod printed in blue PLA on a white Xbox One controller.
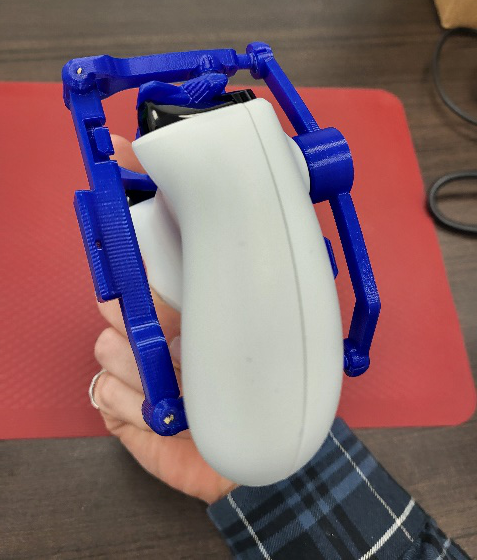
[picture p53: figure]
A picture showing the side view of the right-handed controller mod printed in blue PLA on a white Xbox One controller.

Latch

© 2023 by Makers Making Change. This work is licensed under the CC BY SA 4.0 License: http://creativecommons.org/licenses/by-sa/4.0 Files available at https://makersmakingchange.com/project/one-handed-mods-for-xbox-one-controller Page 1 of 1

V1.0 | February 2023 Right-Handed Mod for Xbox One Controller Assembly Guide

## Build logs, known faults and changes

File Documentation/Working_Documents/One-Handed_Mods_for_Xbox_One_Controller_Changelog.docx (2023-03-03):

# Version 1.0 | 2023/02/23

- Initial designs by Akaki (https://www.printables.com/social/106360-akaki/about) are licensed under Creative Commons (4.0 International License) Attribution – Non-Commercial – Share Alike
- Documentation by Neil Squire / Makers Making Change

© 2023 by Makers Making Change. This work is licensed under the CC BY SA 4.0 License: http://creativecommons.org/licenses/by-sa/4.0 Files available a https://makersmakingchange.com/project/one-handed-mods-for-xbox-one-controller Page 1 of 1

V1.0 | February 2023 One-Handed Mods for Xbox One Controller changelog
